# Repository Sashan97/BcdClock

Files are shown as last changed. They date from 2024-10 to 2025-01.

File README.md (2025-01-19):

This project is a Binary Coded Decimal (BCD) clock with an alarm function, built using miniature incandescent lamps to visually represent time. The clock is based on an Arduino Pro Mini microcontroller and a DS3231 real-time clock (RTC) module for precise timekeeping. The project combines basic timekeeping functionality with a BCD display system, using common components like shift registers and transistors to drive the bulbs.

## Key Features
### BCD Time Display

Time is represented using incandescent bulbs arranged in Binary Coded Decimal format. Each set of bulbs corresponds to the hours, minutes, and seconds in binary. Each column represents one digit.
### Enclosure

The enclosure is partially 3D-printed, while the indicator chassis holding the bulbs is made from aluminum for better heat dissipation.
### Alarm Function

The clock includes an alarm, with a buzzer that activates at the set time. 

### Automatic Display Shutdown

To save power and extend the life of the bulbs, the clock has an automatic display shutdown feature. After a set period, the indicator turns off. The display can be reactivated by pressing a button.
### Power Supply

The clock is powered by a 9V source, with a voltage regulator providing a stable 5V to the components.

## Setup
The clock has 3 set modes. To switch between set modes, press SET key:

_Time (regular mode) -> Time adjust (SET lamp is on) -> Shutdown timer adjust (SET + SLEEP lamps are on) -> Alarm adjust (SET + ALARM lamps are on) -> Time (regular mode)_

- In **time adjust** mode, use **HOURS** and **MINUTES** buttons to set the time.

- In **shutdown timer adjust** mode, use **HOURS** or **MINUTES** button to adjust the shutdown time (traverses in loop betweeen `sleepDelayOptions`)

- In **alarm adjust** mode, use **HOURS** and **MINUTES** buttons to adjust alarm time. Use SNOOZE button to arm the alarm (ALARM lamp is on) or disarm it (ALARM lamp in flashing).
Alarm can also be armed/disarmed by double-pressing the snooze button in regular time display mode.

- When alarm fires, press **SNOOZE** button to postpone the alarm by `SNOOZE_TIME_MINUTES`, or double-press it to disarm the alarm completely.

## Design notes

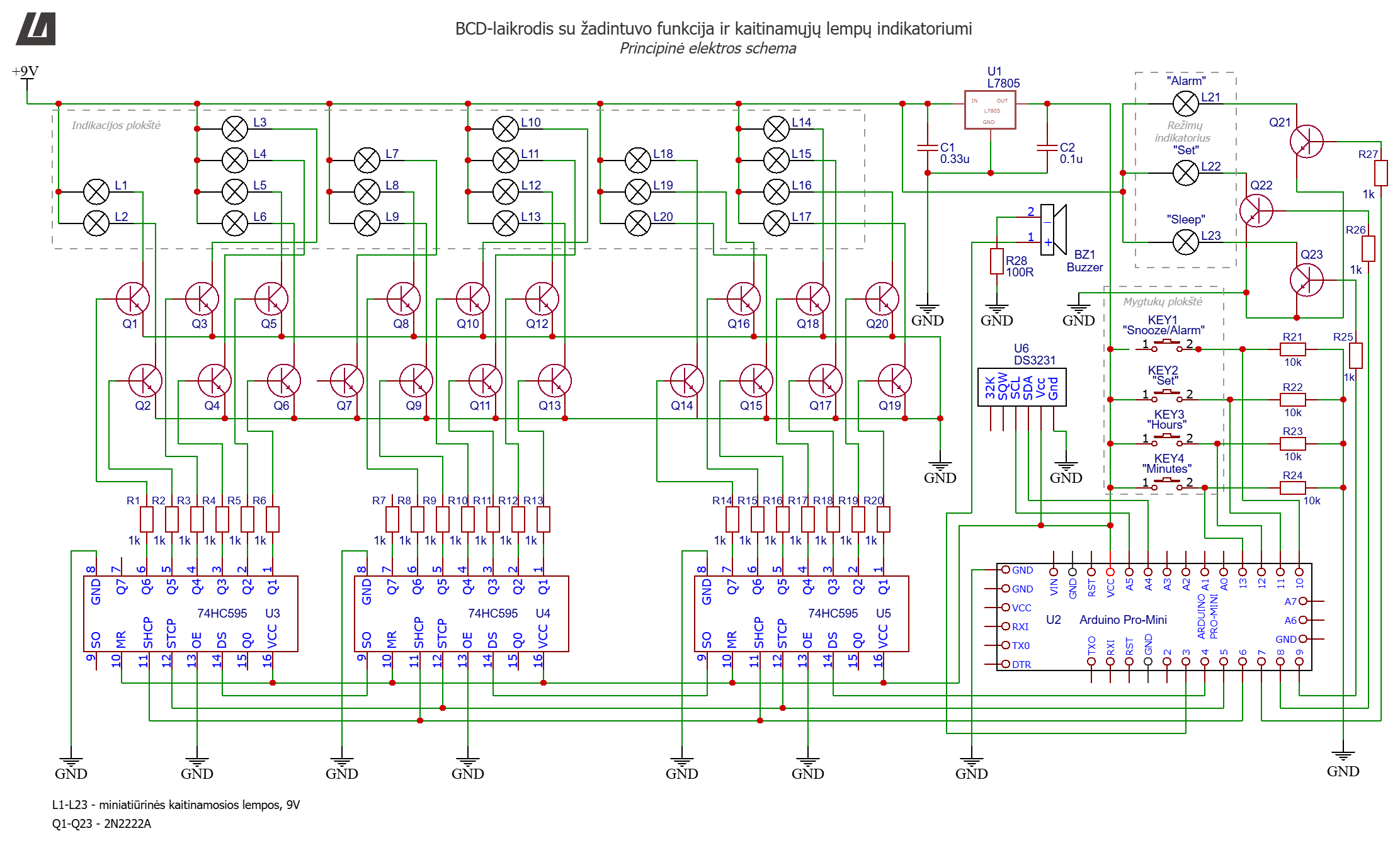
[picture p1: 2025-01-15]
Hardware/circuit_diagram.png

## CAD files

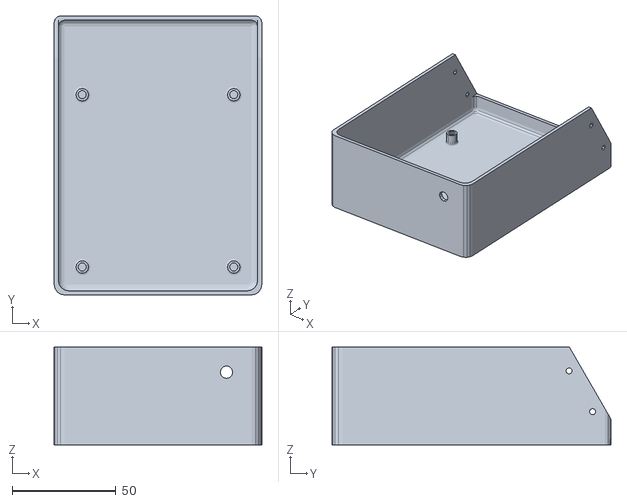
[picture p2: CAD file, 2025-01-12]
Case/stl/case_main.stl
100.0 x 134.4 x 47.0

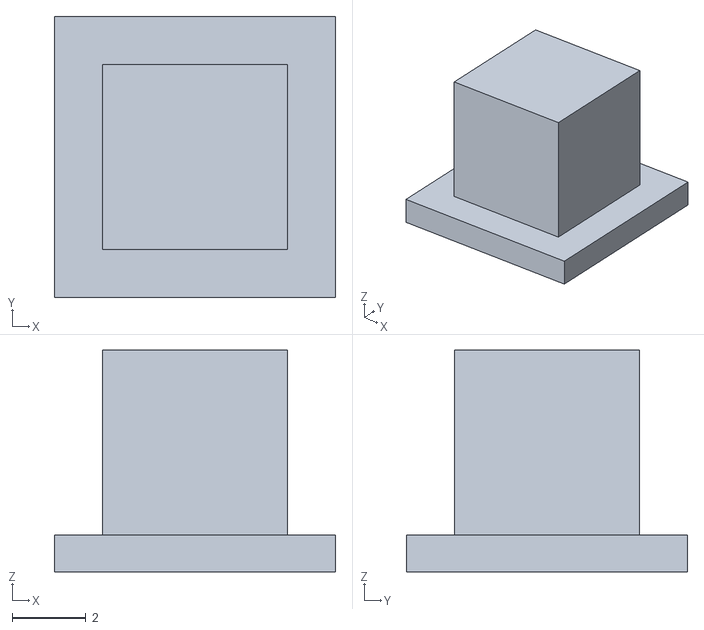
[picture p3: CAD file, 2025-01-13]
Case/stl/button.stl
7.60 x 7.60 x 6.00

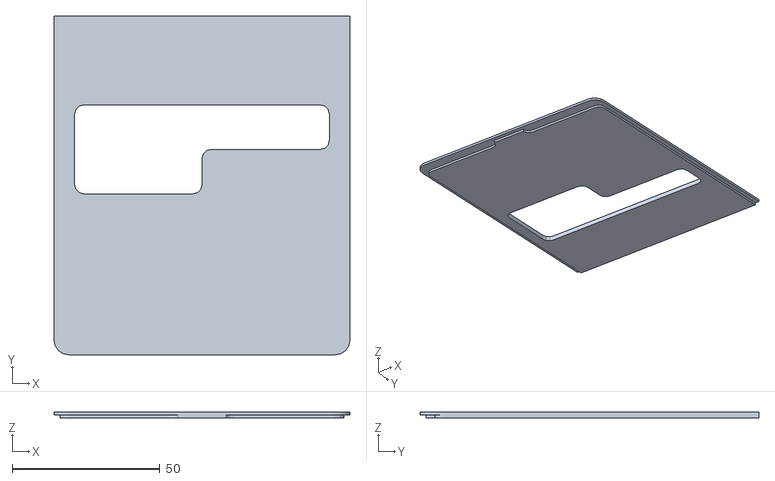
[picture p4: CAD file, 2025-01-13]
Case/stl/Lid.stl
100.0 x 114.4 x 2.00

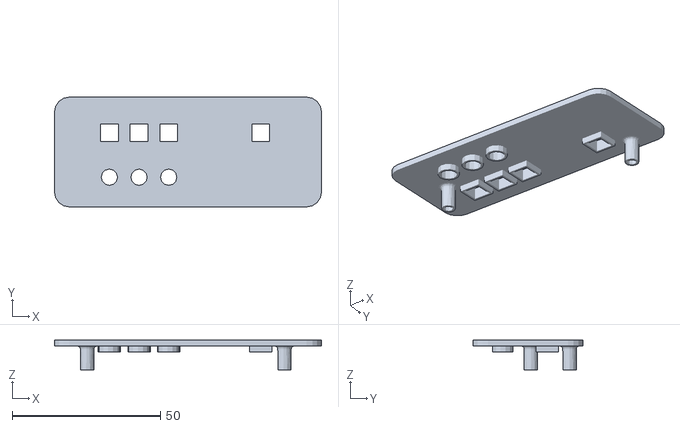
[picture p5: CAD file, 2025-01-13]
Case/stl/keypad.stl
90.0 x 37.0 x 10.0

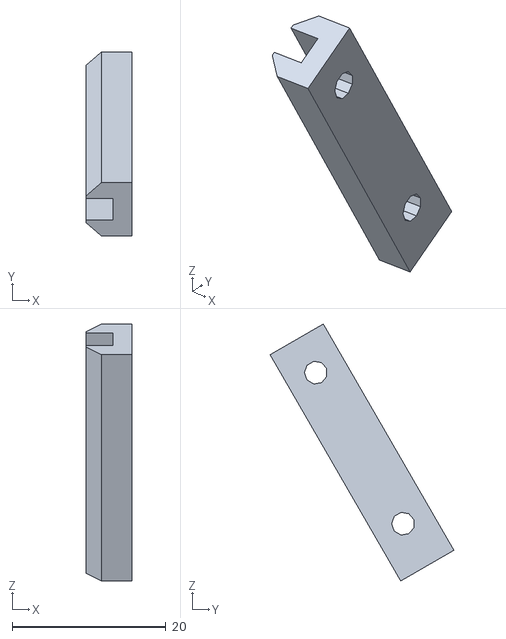
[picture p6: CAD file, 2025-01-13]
Case/stl/rail.stl
6.00 x 23.9 x 33.4

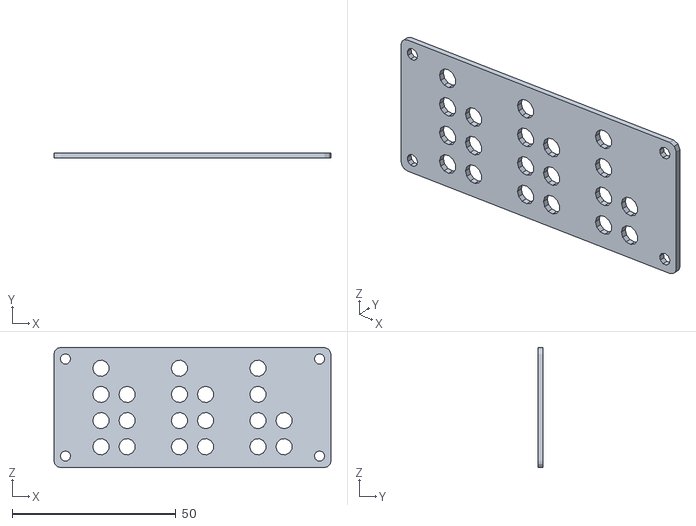
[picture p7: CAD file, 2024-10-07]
Case/stl/ind_base.stl
84.7 x 1.50 x 36.7

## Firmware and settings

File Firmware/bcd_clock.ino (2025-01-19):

#include <RTClib.h>

// Settings
#define SNOOZE_TIME_MINUTES 1
#define ALARM_BUZZER_FREQUENCY_HZ 750
#define DEFAULT_ALARM_HOURS 22
#define DEFAULT_ALARM_MINUTES 24
#define DEFAULT_SLEEP_DELAY_MS 30000
#define DOUBLE_CLICK_THRESHOLD_MS 1000

#define buzzer_pin 3

// Shift register
#define ds_pin 4
#define shcp_pin 6
#define stcp_pin 5

// Mode indication
#define alarmLamp 7
#define setLamp 8
#define sleepLamp 9

// Keyboard
#define snoozeButton 10
#define setButton 11
#define hoursButton 12
#define minutesButton 13

RTC_DS3231 rtc;

unsigned long previousMillis = 0;
const long interval = 1000;

// Variables for button states
int snoozeButtonState = LOW;
int setButtonState = LOW;
int hoursButtonState = LOW;
int minutesButtonState = LOW;

// Variables for previous button states
int lastSnoozeButtonState = LOW;
int lastSetButtonState = LOW;
int lastHoursButtonState = LOW;
int lastMinutesButtonState = LOW;

// Timing variables
unsigned long lastDebounceTimeSnooze = 0; // Timing for debounce
unsigned long lastDebounceTimeSet = 0;    // Timing for debounce
unsigned long lastDebounceTimeHours = 0;  // Timing for debounce
unsigned long lastDebounceTimeMinutes = 0; // Timing for debounce

// Debounce time
const unsigned long debounceDelay = 20;

// Sleep delay in milliseconds. If inactive for this amount of seconds, display will shut down
long sleepDelay = DEFAULT_SLEEP_DELAY_MS;
long sleepDelayOptions[] = { 10000, 30000, 60000, 90000, 120000, 300000, 600000};
int sleepDelayOptionIndex = 1;

unsigned long activityMillis = 0;
unsigned long snoozeDoubleClickTime = 0;

// flag indicating if display should update ot the next loop iteration
bool refreshNeeded;

int hour;
int minute;
int second;

bool alarmArmed = false;
bool alarmFired = false;
bool toneActive = false;
int alarmHour = DEFAULT_ALARM_HOURS;
int alarmMinute = DEFAULT_ALARM_MINUTES;

enum : byte { REGULAR, SET_TIME, SET_SLEEP_DELAY, SET_ALARM_TIME } setMode = REGULAR;

void setup() {
  pinMode(buzzer_pin, OUTPUT);
  pinMode(ds_pin, OUTPUT);
  pinMode(stcp_pin, OUTPUT);
  pinMode(shcp_pin, OUTPUT);

  // Initialize mode indicator pins as output
  pinMode(alarmLamp, OUTPUT);
  pinMode(setLamp, OUTPUT);
  pinMode(sleepLamp, OUTPUT);

  // Initialize button pins as input
  pinMode(snoozeButton, INPUT);
  pinMode(setButton, INPUT);
  pinMode(hoursButton, INPUT);
  pinMode(minutesButton, INPUT);

  Serial.begin(9600);
  rtc.begin();
  rtc.adjust(DateTime(2024,10,15,22,23,30));
}

byte convertToBCD(int seconds) {
  int tens = seconds / 10;
  int ones = seconds % 10;

  byte bcd = (tens << 4) | ones;

  return bcd;
}

void display(int d1, int d2, int d3) {
  // for hours, shift one bit to the left since Q7 is unused
  byte hours = convertToBCD(d1) << 1;
  byte minutes = convertToBCD(d2);
  byte seconds = convertToBCD(d3);

  displayBytes(hours, minutes, seconds);
}

void displayBytes(byte d1, byte d2, byte d3) {
  digitalWrite(stcp_pin, LOW);
  shiftOut(ds_pin, shcp_pin, LSBFIRST, d1);
  shiftOut(ds_pin, shcp_pin, LSBFIRST, d2);
  shiftOut(ds_pin, shcp_pin, LSBFIRST, d3);
  digitalWrite(stcp_pin, HIGH);
}

void displayCurrentTime() {
  DateTime now = rtc.now();
  display(now.hour(), now.minute(), now.second());
}

void handleSnoozeButtonPress() {
  refreshNeeded = true;

  unsigned long clickTime = millis();
  if (clickTime - snoozeDoubleClickTime < DOUBLE_CLICK_THRESHOLD_MS) {
    alarmArmed = !alarmArmed;
    if (!alarmArmed)
      digitalWrite(alarmLamp, LOW);
  }
  snoozeDoubleClickTime = clickTime;

  //TODO: set alarm to current + snooze time
  if (alarmFired) {
    alarmFired = false;
    noTone(buzzer_pin);

    alarmMinute += SNOOZE_TIME_MINUTES;
    while (alarmMinute >= 60) {
      alarmMinute -=60;
      alarmHour++;
      if (alarmHour == 24)
        alarmHour = 0;
    }
  }
  
  if (setMode == SET_ALARM_TIME)
    alarmArmed = !alarmArmed;
}

void changeSleepDelay() {
  sleepDelayOptionIndex++;

  if (sleepDelayOptionIndex > 6)
    sleepDelayOptionIndex = 0;

  sleepDelay = sleepDelayOptions[sleepDelayOptionIndex];
  displayDelay();
}

void displayDelay() {
  int delayInSeconds = sleepDelay / 1000;
  int minutes = delayInSeconds / 60;
  int seconds;

  if (minutes > 0)
    seconds = delayInSeconds - (minutes * 60);
  else
    seconds = delayInSeconds;

  display(0, minutes, seconds);
}

void handleSetButtonPress() {
    setMode = (setMode + 1) % 4;

    refreshNeeded = true;

    if (setMode != REGULAR)
      digitalWrite(setLamp, HIGH);
    else
      digitalWrite(setLamp, LOW);

    if (setMode == SET_SLEEP_DELAY)
      digitalWrite(sleepLamp, HIGH);
    else
      digitalWrite(sleepLamp, LOW);

    if (setMode == SET_ALARM_TIME)
      digitalWrite(alarmLamp, HIGH);
    else
      digitalWrite(alarmLamp, LOW);

}

void handleHoursButtonPress() {
  if (setMode == SET_TIME)
  {
    DateTime current = rtc.now();

    int hours = current.hour();
    hours++;
    if (hours == 24) hours = 0;

    DateTime newDateTime(
      current.year(), 
      current.month(), 
      current.day(),
      hours,
      current.minute(), 
      current.second()
    );

    rtc.adjust(newDateTime);
    display(newDateTime.hour(), newDateTime.minute(), 0);
  }
  else if (setMode == SET_SLEEP_DELAY)
    changeSleepDelay();
  else if (setMode == SET_ALARM_TIME) {
    alarmHour++;
    if (alarmHour >= 24)
      alarmHour = 0;
  }
}

void handleMinutesButtonPress() {
  if (setMode == SET_TIME)
  {
    DateTime current = rtc.now();

    int minutes = current.minute();
    minutes++;
    if (minutes == 60) minutes = 0;

    DateTime newDateTime(
      current.year(), 
      current.month(), 
      current.day(),
      current.hour(),
      minutes, 
      current.second()
    );

    rtc.adjust(newDateTime);
    display(newDateTime.hour(), newDateTime.minute(), 0);
  }
  else if (setMode == SET_SLEEP_DELAY)
    changeSleepDelay();
  else if (setMode == SET_ALARM_TIME) {
    alarmMinute++;
    if (alarmMinute >= 60)
      alarmMinute = 0;
  }
}

void handleButton(int buttonPin, int &buttonState, int &lastButtonState, unsigned long &lastDebounceTime, void (*buttonAction)()) {
    int reading = digitalRead(buttonPin); // Read the current state

    // Check if the button state has changed
    if (reading != lastButtonState) {
        lastDebounceTime = millis(); // Reset debounce timer
    }
    
    // If the state has stabilized beyond debounce delay, check for changes
    if ((millis() - lastDebounceTime) > debounceDelay) {
        if (reading != buttonState) {
            buttonState = reading; // Update button state
            // Only take action if the button is pressed (HIGH)
            if (buttonState == HIGH) {
              activityMillis = millis();
              buttonAction(); // Call the specific action function
            }
        }
    }
    
    lastButtonState = reading; // Save reading for the next loop
}

void loop() {

  refreshNeeded = false;

  handleButton(snoozeButton, snoozeButtonState, lastSnoozeButtonState, lastDebounceTimeSnooze, handleSnoozeButtonPress);
  handleButton(setButton, setButtonState, lastSetButtonState, lastDebounceTimeSet, handleSetButtonPress);
  handleButton(hoursButton, hoursButtonState, lastHoursButtonState, lastDebounceTimeHours, handleHoursButtonPress);
  handleButton(minutesButton, minutesButtonState, lastMinutesButtonState, lastDebounceTimeMinutes, handleMinutesButtonPress);

  unsigned long currentMillis = millis();
  // Refresh time once per second
  if (currentMillis - previousMillis >= interval)
  {
    previousMillis = currentMillis;

    DateTime current = rtc.now();
    hour = current.hour();
    minute = current.minute();
    second = current.second();

    refreshNeeded = true;

    if (alarmArmed && hour == alarmHour && minute == alarmMinute)
      alarmFired = true;
  }

  if (alarmFired && refreshNeeded) {
    activityMillis = currentMillis;
    if (!toneActive) {
      tone(buzzer_pin, ALARM_BUZZER_FREQUENCY_HZ);
      toneActive = true;
    }
    else {
      noTone(buzzer_pin);
      toneActive = false;
    }
  }

  if (setMode == REGULAR) {
    if (millis() - activityMillis >= sleepDelay) {
      display(0, 0, 0);
      digitalWrite(alarmLamp, LOW);
    }
    else {
      if (alarmArmed) {
        digitalWrite(alarmLamp, HIGH);
      }
      if (refreshNeeded) {
        display(hour, minute, second);
      }
    }
  }
  else if (setMode == SET_TIME) {
    if (refreshNeeded) {
      display(hour, minute, 0);
    }
  }
  else if (setMode == SET_SLEEP_DELAY) {
    displayDelay();
  }
  else if (setMode == SET_ALARM_TIME) {
    display(alarmHour, alarmMinute, 0);

    // if alarm is not armed - alarm lamp blinks
    if (!alarmArmed) {
      if (refreshNeeded) {
        bool currentLampState = digitalRead(alarmLamp);
        digitalWrite(alarmLamp, !currentLampState);
      }
    }
    else
      digitalWrite(alarmLamp, HIGH);
  }
}

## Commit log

2024-10-07 Added initial files
    [ind_base.stl]
2024-10-14 Update circuit diagram, add separate resistors for each key
2024-10-20 Change button and lamp designations
2024-10-23 Fix delay after entering set mode
    [bcd_clock.ino]
2024-10-30 Added alarm buzzer support
    [bcd_clock.ino]
2024-12-16 Add PCB 3d models
2025-01-12 Begin case development
2025-01-12 Case improvements
    [case_main.stl]
2025-01-13 Complete case development
    [Lid.stl, button.stl, keypad.stl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]
2025-01-15 Redesigned mode indication power supply
2025-01-19 Fixed hours overflow in alarm setup mode
    [bcd_clock.ino]
